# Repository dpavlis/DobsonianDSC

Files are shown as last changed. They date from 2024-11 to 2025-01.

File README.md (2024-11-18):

# DobsonianDSC

---
### High-light of changes implemented compared to original
* Support for buzzer to indicate the system is up and additional signals
* Support for reset-switch to reset counters of encoders and reset the whole system (if long-pressed)
* Configuration extended to enable setting starting points of encoder counters (to allow setting different than 0 count - for example, if the default position of the scope is towards Zenith)
---
Amateur astronomers want to know where their telescope is pointing at. For this reason, many commercial telescopes (like the Orion IntelliScope) come equipped with "push to" features, often based on high precision optical rotary encoders attached to the telescope mount, and a hand control device with a database of coordinates of thousands of stars and other sky objects.

There are also commercial Digital Setting Circles, which are kits sold for telescope owners to adapt to their existing telescope, in order to give it "push to" features, costing a few hundred dollars.

The mobile app [SkySafari](https://skysafariastronomy.com/) comes with a celestial database that is often more up-to-date, and it's user interface (a visual representation of the night sky) can be considered superior to what text lines on a push-to hand controller allow.

This project is an open source implementation of Digital Setting Circles for dobsonian telescopes. By using two inexpensive optical encoders and an ESP32 microcontroller it enables amateur astronomers to connect their dobsonian telescope to the SkySafari app.

Particular emphasis has been placed on making sure anybody can build the circuit regardless of their experience (or lack thereof) with electronics or arduino, including a step-by-step guide for a very simple implementation that requires no soldering.

This DSC achieves the following:

* Absolute minimum number of components, making it simple and inexpensive. (The bill of materials is under **$40**)
* Easy to build, no soldering required.
* Wireless communication with the SkySafari app, No need for a wired handheld control.
* Ability to connect to an external WiFi (to maintain access to the internet while using the DSC)
* Web configuration page for easily configuring everything: WiFi settings/password, encoder resolutions, flipping encoder pins, notification API/keys, device name.
* Bluetooth support.

This is what it looks like installed on a small tabletop dobsonian:

Mini Dob with DSC

## Documentation

  * This [Arduino IDE guide](https://github.com/vlaate/DobsonianDSC/blob/master/docs/ArduinoIDE.md) will provide beginner-friendly step by step instructions on how to install and configure the Arduino IDE on your computer, including the board managers and libraries required by the DSC, so that you can upload this software to an ESP-32 microcontroller.
  * This [Upload and Configuration guide](https://github.com/vlaate/DobsonianDSC/blob/master/docs/UploadConfigure.md) provides step by step instructions on how to upload the DSC software to the ESP32 microcontroller, how to configure the DSC using it's web configuration interface, and how to connect the SkySafari app to it.
  * The [Circuit Building Guide](https://github.com/vlaate/DobsonianDSC/blob/master/docs/Solderless.md) contains the circuit schematics, the parts list and a step-by-step instructions on how to assemble a beginner-friendly **solderless** implementation of the circuit.
  * You can ask questions or provide feedback in the [CloudyNights forums](https://www.cloudynights.com/topic/589521-37-dobsonian-dsc-for-diy-makers/).
  * Useful information on how to attach altitude encoders to dobsonians can be found [here](https://www.cloudynights.com/topic/772803-how-to-attach-altitude-encoders-to-dobsonians/)

## Pictures

Close up AZ
Alt Encoder 1
Alt Encoder 2
Components
Web Configuration

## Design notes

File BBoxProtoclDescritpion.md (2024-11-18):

# Known DSC Commands

Thanks to https://github.com/synfinatic/teensy-dsc for following summary:

### BBox/Sky Wizard CTI
 
Command | Description | Example Input | Example Output | Notes
--------|-------------|---------------|----------------|------
Z# # | Set encoder resolution | R10000\<TAB\>-10000\<CR\> | * | RA/Az, Dec/Alt
P | Status | P | 001 | Hard coded value to mean no errors, battery OK
Q | Get encoder position | Q | +01234\<TAB\>-00045\<CR\> | 

Notes:

 * Each numerical value must be 6 characters.
 * Unclear if both \<Tab\> and \<SP\> are allowed, but I think so.  Tabs are preferred?

### Orion Intelliscope 
 
Command | Description | Example Input | Example Output | Notes
--------|-------------|---------------|----------------|------
Q | Get encoder position | Q | +01234\<TAB\>-00045\<CR\> | 
P | Status | P | P001 | Hard coded value to mean no errors, battery OK

Notes:

 * At startup, the Intelliscope sends it's version string: V1.14
 * Each numerical value must be 6 characters.

### NGC Max
 
Command | Description | Example Input | Example Output | Notes
--------|-------------|---------------|----------------|------
Q | Get encoder position | Q | +01234\<TAB\>-00045 | Unlike Intelliscope, no \<CR\> at the end

### Basic Encoder System????

Command | Description | Example Input | Example Output | Notes
--------|-------------|---------------|----------------|------
v | Version | v | TeensyDSC v1.0\<CR\> |
V | Version | V | TeensyDSC v1.0\<CR\> |
R# # | Set encoder resolution | R10000 -10000\<CR\> | R | RA/Az, Dec/Alt
H | Get encoder resolution | H | 10000 -10000\<CR\> | 
r | Get encoder resolution | r | 10000 -10000\<CR\> |
A | Check connection | A | Y |
a | Check connection | a | Y |

### Additional TeensyDSC Commands

Command | Description | Example Input | Example Output | Notes
--------|-------------|---------------|----------------|------
? | CLI Help | ? | \<multiple lines...\> |

### Ouranos / Sky Guider III

Command | Description | Example Input | Example Output | Notes
--------|-------------|---------------|----------------|------
Q | Get encoder position | Q | +01234\<TAB\>-00045\<CR\> | Unsure about Tab/CR
R# # | Set encoder resolution | R10000 -10000 | R | RA/Az, Dec/Alt.  Unsure about Tab/CR 
I# # | Set encoder position | I0 0 | R | Unsure about Tab/CR
A | Set init flag | A | \<Unknown\> | No need to support
a | Get init flag | a | \<Unknown\> | No need to support

---

Thanks to ChatGPT for following summary ;-)

# BBox Protocol for Telescope Control

The BBox protocol is a communication standard used by telescope control systems and digital setting circles (DSCs) to interface with astronomy software for precise control and tracking of celestial objects. It operates over a serial connection (often RS-232) and allows the software to receive and interpret data from encoders mounted on the telescope's axes. The protocol includes commands for querying and configuring the telescope's position, encoder settings, and other operational parameters.

## Key Commands in the BBox Protocol

### 1. Q Command (Query Encoder Position)
- **Purpose**: Retrieves the current encoder counts for the azimuth (horizontal) and altitude (vertical) axes, representing the telescope's pointing position.
- **Command Format**:

Q

- **Response Format**:

azimuth_count, altitude_count

- **Example Interaction**:
- **Sent Command**: `Q`
- **Response**: `123456,654321`
- Here, `123456` is the encoder count for the azimuth axis, and `654321` is the encoder count for the altitude axis. These counts are used by the software to determine the telescope's exact pointing coordinates.

### 2. H Command (Set Home Position)
- **Purpose**: Resets or defines a "home" or reference position for the telescope’s encoders.
- **Command Format**:

H

- **Response Format**:

OK

- **Example Interaction**:
- **Sent Command**: `H`
- **Response**: `OK`
- `OK` confirms that the home position has been set successfully. This position can be used as a baseline for alignment or recalibration purposes.

### 3. G Command (Get Encoder Resolution)
- **Purpose**: Retrieves the encoder resolution, which represents the number of steps per full revolution for each axis.
- **Command Format**:

G

- **Response Format**:

azimuth_resolution, altitude_resolution

- **Example Interaction**:
- **Sent Command**: `G`
- **Response**: `4096,8192`
- Here, `4096` is the azimuth resolution, and `8192` is the altitude resolution, representing the number of encoder steps per revolution for each axis.

### 4. Z Command (Reset Encoders)
- **Purpose**: Resets the encoder counts to zero or a predefined starting position.
- **Command Format**:

Z

- **Response Format**:

OK

- **Example Interaction**:
- **Sent Command**: `Z`
- **Response**: `OK`
- This response confirms that the encoder counts have been reset successfully. After resetting, the telescope is ready for further alignment or movement instructions.

### 5. S Command (Set Encoder Resolution)
- **Purpose**: Configures the encoder resolution, specifying the number of steps per full revolution for both azimuth and altitude axes.
- **Command Format**:

S azimuth_resolution, altitude_resolution

- **Response Format**:

OK

- **Example Interaction**:
- **Sent Command**: `S 4096,8192`
- **Response**: `OK`
- This confirms that the encoder resolution has been set to 4096 steps per revolution for the azimuth axis and 8192 steps per revolution for the altitude axis.

### 6. T Command (Toggle Tracking)
- **Purpose**: Enables or disables tracking to keep the telescope aligned with a specific celestial object.
- **Command Format**:

T on/off

- **Response Format**:

OK

- **Example Interaction**:
- **Sent Command**: `T on`
- **Response**: `OK`
- This indicates that tracking has been enabled. Similarly, sending `T off` would disable tracking.

### 7. C Command (Set Calibration)
- **Purpose**: Applies a calibration factor or offset to correct for mechanical inaccuracies in the telescope mount or encoder setup.
- **Command Format**:

C calibration_value

- **Response Format**:

OK

- **Example Interaction**:
- **Sent Command**: `C 5`
- **Response**: `OK`
- This confirms that a calibration factor of 5 has been applied.

### 8. E Command (Error Query)
- **Purpose**: Retrieves any error codes or status flags from the digital setting circle, assisting with diagnostics or troubleshooting.
- **Command Format**:

E

- **Response Format**:

error_code

- **Example Interaction**:
- **Sent Command**: `E`
- **Response**: `0`
- A response of `0` typically means no error is present. Non-zero values would indicate specific error codes, which may require consulting device documentation for interpretation.

## Summary of Common Command Responses

| Command | Description | Example Sent | Example Response |
|---|---|---|---|
| `Q` | Query Encoder Position | `Q` | `123456,654321` |
| `H` | Set Home Position | `H` | `OK` |
| `G` | Get Encoder Resolution | `G` | `4096,8192` |
| `Z` | Reset Encoders | `Z` | `OK` |
| `S` | Set Encoder Resolution | `S 4096,8192`| `OK` |
| `T` | Toggle Tracking | `T on` | `OK` |
| `C` | Set Calibration | `C 5` | `OK` |
| `E` | Error Query | `E` | `0` |

Each command in the BBox protocol plays a crucial role in aligning, configuring, and operating the telescope. By understanding the function and response format of each command, users can accurately control and adjust the telescope’s movement, alignment, and tracking capabilities with compatible software applications.

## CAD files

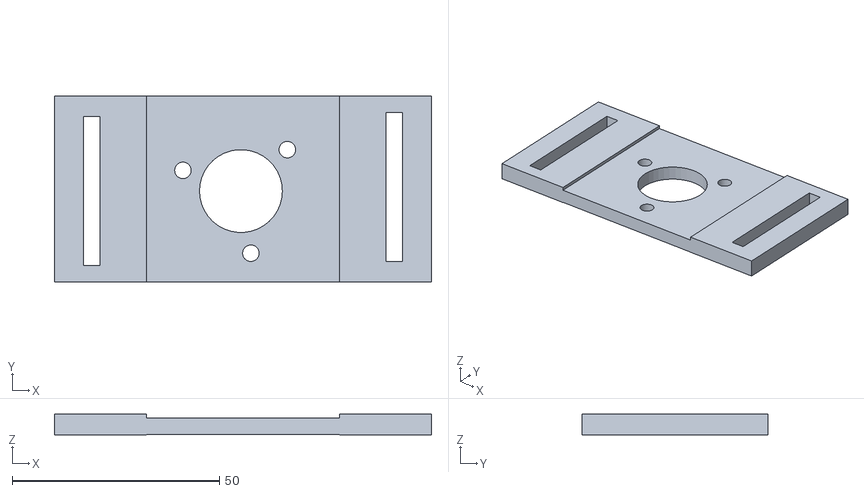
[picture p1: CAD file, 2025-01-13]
STLs/HolderScientific.stl
91.0 x 45.0 x 5.05

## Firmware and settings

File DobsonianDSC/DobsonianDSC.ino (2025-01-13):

/*
  Dual Encoder Digital Setting Circles for ESP32 microcontrollers

  This is a simple adapter to connect two inexpensive incremental optical encoders
  via WiFi and/or BlueTooth to astronomy apps such as SkySafari,
  in order to provide "Push To" style features to dobsonian style telescope mounts.

  Copyright (c) 2017-2021 Vladimir Atehortúa. All rights reserved.

  This program is free software: you can redistribute it and/or modify
  it under the terms of the version 3 GNU General Public License as
  published by the Free Software Foundation.
  This program is distributed in the hope that it will be useful,
  but WITHOUT ANY WARRANTY; without even the implied warranty of
  MERCHANTABILITY or FITNESS FOR A PARTICULAR PURPOSE.  See the
  GNU General Public License for more details.
  You should have received a copy of the GNU General Public License along with this program.
  If not, see <http://www.gnu.org/licenses/>
*/

/**
    Hardware used:
    ESP-32S Development Board, I used a generic one: https://www.aliexpress.com/item/32800930387.html?
    Two Optical Encoders with NPN (a.k.a. "N channel") "Open Collector" (a.k.a. "open drain") output, I used some 600 p/r generic ones: https://www.aliexpress.com/item/32669741048.html
    Dupont cables or other suitable connectors.
    Power supply (could be a 5V USB power bank)

    ESP32 pinout:
     IMPORTANT: Only encoders with NPN Open collector outputs can be connected directly to the pins of the ESP32. Other encoders might require level shifters.
     AZ_Encoder_A = GPIO18 = D18  (or change it in the #define code below)
     AZ_Encoder_B = GPIO19 = D19  (or change it in the #define code below)
     ALT_Encoder_A = GPIO25 = D25 (or change it in the #define code below)
     ALT_Encoder_B = GPIO26 = D26 (or change it in the #define code below)
     VIN = Encoder VCC (and if you don't use a USB power bank, this would also connect to your 5V power source)
     GND = Encoder GND
*/

/**
   Required Additional Board Managers for the Arduino IDE (File->Preferences):
   https://dl.espressif.com/dl/package_esp32_index.json

   Required libraries for the Arduino IDE (Tools -> Manage Libraries):
   ESP32Encoder by Kevin Harrington, see https://github.com/madhephaestus/ESP32Encoder
   ArduinoJson by Benoit Blanchon, see https://arduinojson.org/
*/

#include <WiFi.h>
#include <WebServer.h>
#include <ESPmDNS.h>
#include <HTTPClient.h>
#include <ESP32Encoder.h>
#include "WebConfig_DSC.h"
#include "BluetoothSerial.h"
#include "note_frequencies.h"
#if !defined(CONFIG_BT_ENABLED) || !defined(CONFIG_BLUEDROID_ENABLED)
#error Bluetooth is not enabled! Please run `make menuconfig` to and enable it
#endif

//#define DEBUG_PROTOCOL //for priting debug messages when handling protocol

// Choose which pins of the ESP32 to use for the Azimuth Encoder
ESP32Encoder AZencoder;
#define PIN_AZ_A 18 // Important: Not all encoders can be connected directly to the pins of the ESP32, read more about this in the project's github page
#define PIN_AZ_B 19

#define AZIMUTH_RES 12000 //1000 pulses per revolution, programmed in quadrature for 1000 x 4 = 4000 pulses, geared 1:3 = 12000
#define AZIMUTH_START 0 //starts at 0 - NORTH

// Choose which pins of the ESP32 to use for the Altitude Encoder
ESP32Encoder ALTencoder;
#define PIN_ALT_A 25
#define PIN_ALT_B 26

#define ALTITUDE_RES 22140 //ticks per rotation : 1000 x 4 = 4000 pulses, geared ??
#define ALTITUDE_START 5624  //starts at 5624  - 90+ degrees (parked)

#define AP_WIFI_NETWORK "ExploreScientific_DSC"

#define MAX_SRV_CLIENTS  3   // How many clients can connect simultaneously to the DSC.
#define MAX_REQUEST_LENGTH 30 // Maximum length of request from client to process 

//beeper for signalling
#define PIN_BEEPER 32
//count-reset button
#define PIN_RESET 33
#define RESTART_HOLD_TIME 3000 // 3s - 3000ms
#define PIN_RESET_WAIT_TIME 50

unsigned int melodyStart[] = {NOTE_C, NOTE_E, NOTE_G, NOTE_0, NOTE_C, NOTE_E, NOTE_G, NOTE_FINISH};
unsigned int melodyError[] = {NOTE_C, NOTE_C, NOTE_G, NOTE_G, NOTE_C, NOTE_C, NOTE_G, NOTE_G, NOTE_FINISH};
unsigned int melodySetupCompleted[] = {NOTE_C, NOTE_0, NOTE_C, NOTE_0, NOTE_C, NOTE_0, NOTE_G, NOTE_G, NOTE_G, NOTE_G, NOTE_FINISH};

BluetoothSerial SerialBT;

String params = "["
                "{"
                "'name':'ssid',"
                "'label':'WiFi SSID Name',"
                "'type':" + String(INPUTTEXT) + ","
                "'default':''"
                "},"
                "{"
                "'name':'pwd',"
                "'label':'WiFi Password',"
                "'type':" + String(INPUTPASSWORD) + ","
                "'default':''"
                "},"
                "{"
                "'name':'btname',"
                "'label':'Bluetooth device Name',"
                "'type':" + String(INPUTTEXT) + ","
                "'default':'Telescope'"
                "},"
                "{"
                "'name':'azsteps',"
                "'label':'Azimuth Steps',"
                "'type':" + String(INPUTNUMBER) + ","
                "'min':1,'max':10000000,"
                "'default':'" + AZIMUTH_RES + "'"
                "},"
                "{"
                "'name':'azstart',"
                "'label':'Azimuth Start Position',"
                "'type':" + String(INPUTNUMBER) + ","
                "'min':0,'max':10000000,"
                "'default':'" + AZIMUTH_START + "'"
                "},"
                "{"
                "'name':'alsteps',"
                "'label':'Altitude Steps',"
                "'type':" + String(INPUTNUMBER) + ","
                "'min':1,'max':10000000,"
                "'default':'"+ ALTITUDE_RES + "'"
                "},"
                "{"
                "'name':'alstart',"
                "'label':'Altitude Start Position',"
                "'type':" + String(INPUTNUMBER) + ","
                "'min':0,'max':10000000,"
                "'default':'"+ ALTITUDE_START + "'"
                "},"
                "{"
                "'name':'flpaz',"
                "'label':'Flip Azimuth',"
                "'type':" + String(INPUTCHECKBOX) + ","
                "'default':'1'"
                "},"
                "{"
                "'name':'flpalt',"
                "'label':'Flip Altitude',"
                "'type':" + String(INPUTCHECKBOX) + ","
                "'default':'1'"
                "},"
                "{"
                "'name':'apikey',"
                "'label':'Notification API Key (optional)',"
                "'type':" + String(INPUTTEXT) + ","
                "'max':35,"
                "'default':''"
                "},"
                "{"
                "'name':'userkey',"
                "'label':'Notification User Key (optional)',"
                "'type':" + String(INPUTTEXT) + ","
                "'max':35,"
                "'default':''"
                "}"
                "]";

WebServer server;
WiFiServer TCPserver(4030);                 // 4030 is the TCP port Skysafari usually expects for "Basic Encoder Systems"
WiFiClient serverClients[MAX_SRV_CLIENTS];
WebConfig conf;

boolean initWiFi() {
  boolean connected = false;
  WiFi.mode(WIFI_STA);
  Serial.print("Connecting to ");
  Serial.print(conf.values[0]);
  Serial.println(" SSID");
  if (conf.values[0] != "") {
    WiFi.begin(conf.values[0].c_str(), conf.values[1].c_str());
    uint8_t cnt = 0;
    while ((WiFi.status() != WL_CONNECTED) && (cnt < 20)) {
      delay(500);
      Serial.print(".");
      cnt++;
    }
    Serial.println();
    if (WiFi.status() == WL_CONNECTED) {
      Serial.print("IP Adress:");
      Serial.println(WiFi.localIP());
      connected = true;
      // We can use the Pushover service to send a notification to your smartphone, an easy way to obtain the IP address that was assigned to the device:
      if (conf.getValue("apikey") != "" && conf.getValue("userkey") != "")
      {
        HTTPClient http;
        http.begin("https://api.pushover.net/1/messages.json");
        http.addHeader("Content-Type", "application/x-www-form-urlencoded");
        char _header[300];
        sprintf(_header, "token=%s&user=%s&message=Telescope-DSC connected to SSID:[%s] IP Address: [%s]", conf.getValue("apikey"), conf.getValue("userkey"), WiFi.SSID(), WiFi.localIP().toString().c_str());
        int httpResponseCode = http.POST(_header);
        http.end();
      }
    }
  }
  if (!connected) { // if unable to connect to an external WiFi, let's launch our own passwordless WiFi SSID:
    WiFi.mode(WIFI_AP);
    WiFi.softAP(AP_WIFI_NETWORK, "", 1);
  }
  return connected;
}

// method that handles the clicks on "SAVE" and "RESET" buttons on the web config form
void handleRoot() {
  conf.handleFormRequest(&server);
  if (server.hasArg("SAVE"))
  {
    uint8_t cnt = conf.getCount();
    for (uint8_t i = 0; i < cnt; i++)
    {
      Serial.print(conf.getName(i));
      Serial.print(" = ");
      Serial.println(conf.values[i]);
    }
  }
}

/**
   Configure encoders using the ESP32Encoder library by Kevin Harrington.
   This uses the ESP32's hardware pulse counters, not polling nor interrupts!
   In my tests, two encoders can get simultaneous quadrature pulses at 20Khz without missing a step.
*/
void setupEncoders()
{
  // It's very important to enable pull up resistors in order to work with the NPN open collector outputs:
  ESP32Encoder::useInternalWeakPullResistors = puType::up;

  // flip the pins used by Altitude encoder if the web configuration says so:
  if (conf.getBool("flpalt"))
  {
    ALTencoder.attachFullQuad(PIN_ALT_A, PIN_ALT_B);
  }
  else
  {
    ALTencoder.attachFullQuad(PIN_ALT_B, PIN_ALT_A);
  }
  ALTencoder.setFilter(0); // filters are only needed for cheap mechanical/switch encoders such as the Keyes KY-040, not by the 600p/s encoders

  // flip the pins used by Azimuth encoder if the web configuration says so:
  if (conf.getBool("flpaz"))
  {
    AZencoder.attachFullQuad(PIN_AZ_B, PIN_AZ_A);
  }
  else
  {
    AZencoder.attachFullQuad(PIN_AZ_A, PIN_AZ_B);
  }
  AZencoder.setFilter(0); // filters are only needed for cheap mechanical/switch encoders such as the Keyes KY-040, not by the 600p/s encoders

  // set starting count value after attaching
  ALTencoder.clearCount(); //reset counter
  ALTencoder.setCount(conf.getInt("alstart")); //set starting point
  AZencoder.clearCount();
  AZencoder.setCount(conf.getInt("azstart"));
}

void processBBoxCommand(char command,char details[], char response[]) 
{
   switch (command)
        {
          case 'Q':   // the Query command, sent by SkySafari and others as the "Basic Encoder protocol" to query for encoder values.
            sprintf(response, "%lld\t%lld\t\n", AZencoder.getCount(), ALTencoder.getCount());
            break;
          case 'G': // G Command (Get Encoder Resolution) -- duplicate to 'H' ??
            snprintf(response, 20, "%d-%d\n", conf.getInt("azsteps"), conf.getInt("alsteps"));
            break;
          case 'H':   // 'H' - request for encoder resolution, e.g. 10000-10000\n
            //snprintf(response, 20, "%d-%d\n", conf.getInt("azsteps"), conf.getInt("alsteps"));
            snprintf(response, 20, "%d\t%d\t\n", conf.getInt("azsteps"), conf.getInt("alsteps"));
            break;
          case 'Z': // 'Z' - Z Command (Reset Encoders)
            ALTencoder.clearCount();
            AZencoder.clearCount();
            sprintf(response, "OK\n");
            break;
          case 'S': // 'S' S Command (Set Encoder Resolution) - S azimuth_resolution, altitude_resolution
            //S azimuth_resolution, altitude_resolution
            int altRes, azRes;
            if (sscanf(details, "%d,%d", &azRes, &altRes) == 2) {
              char strval[20];
              itoa(azRes,strval,10);
              conf.setValue("azsteps",strval);
              itoa(altRes,strval,10);
              conf.setValue("alsteps",strval);
              sprintf(response, "OK\n");
            }
            break;
          case 'R': // Not A BBox command - reset counters (for debugging mostly)
            ALTencoder.clearCount(); 
            AZencoder.clearCount();
            sprintf(response, "OK\n");
            break;
          default: sprintf(response,"\n");
            #ifdef DEBUG_PROTOCOL
              Serial.print("*** UNKNOWN COMMAND ****");
            #endif
        }
    #ifdef DEBUG_PROTOCOL
    Serial.printf("[%c]{%s}(%s)\n",command,details,response);
    #endif

}

void attendTcpRequests()  // handle connections from SkySafari and similar software via TCP on port 4030
{
  uint8_t i;
  // check for new clients trying to connect
  if (TCPserver.hasClient()) {
    for (i = 0; i < MAX_SRV_CLIENTS; i++) {
      // find a free or disconnected spot:
      if (!serverClients[i] || !serverClients[i].connected()) {
        if (serverClients[i]) {
          serverClients[i].stop();
        }
        serverClients[i] = TCPserver.available();
        // the new client has connected
        #ifdef DEBUG_PROTOCOL
          Serial.print("New client connected: ");
          Serial.println(serverClients[i].remoteIP());
        #endif
        break;
      }
    }
    // when there are no free/disconnected spots, reject the new client:
    if (i == MAX_SRV_CLIENTS) {
      WiFiClient serverClient = TCPserver.available();
      serverClient.stop();
      #ifdef DEBUG_PROTOCOL
          Serial.println("Client rejected. No more free spots.");
      #endif
    }
  }

  // check what the client sends for "Basic Encoder protocol" commands:
  for (i = 0; i < MAX_SRV_CLIENTS; i++)
  {
    if (serverClients[i] && serverClients[i].connected())
    {
      if (serverClients[i].available())
      {
        #ifdef DEBUG_PROTOCOL
        Serial.printf("TCP [%s:%u]",serverClients[i].remoteIP().toString(),serverClients[i].remotePort());
        #endif
        char command = serverClients[i].read(); // read the first character received, usually the command
        char requestDetails[MAX_REQUEST_LENGTH+1];
        int count=0;
        if (serverClients[i].available() && count < MAX_REQUEST_LENGTH){
          requestDetails[count] = serverClients[i].read();
          count++;
        }
        requestDetails[count]='\0';
        while (serverClients[i].available())
        {
            serverClients[i].read(); // flushing the remaining input buffer (if there are more chars than fit to request details)
        }
        char response[30];
        processBBoxCommand(command,requestDetails,response);
        serverClients[i].println(response);
      }
    }
  }
}

void attendBTRequests()   // handle connections from SkySafari and similar software via BlueTooth
{
  if (SerialBT.available()) {
    //WiFi.disconnect();
    //WiFi.mode(WIFI_OFF);

    char command = SerialBT.read();
    char requestDetails[MAX_REQUEST_LENGTH+1];
    int count=0;
    while (SerialBT.available() && count < MAX_REQUEST_LENGTH)
    {
      requestDetails[count] = SerialBT.read();
      count++;
    }
    requestDetails[count]='\0';
    while (SerialBT.available())
    {
      SerialBT.read();  // flushing the remaining input buffer (if there are more chars than fit to request details)
    }

    #ifdef DEBUG_PROTOCOL
    Serial.print("BT: ");
    #endif
    char response[30];
    processBBoxCommand(command,requestDetails,response);

    #ifdef DEBUG_PROTOCOL
    if (command=='?') printConfig();
    #endif

    SerialBT.println(response);
  }
}

void printConfig(){
    for(int i=0; i<conf.getCount();i++){
      SerialBT.print(conf.getName(i));
      SerialBT.print(" : ");
      SerialBT.println(conf.getValue(conf.getName(i).c_str()));
    }
}

void playMelody(const unsigned int melody[]){
   for(int i=0; melody[i]!=NOTE_FINISH; i++){
     tone(PIN_BEEPER, melody[i], 300);
   }
}

/**
 * Arduino main setup method
 */
void setup() {
  Serial.begin(115200);
  Serial.println(params);
  playMelody(melodyStart);
  pinMode(PIN_RESET, INPUT_PULLDOWN);

  conf.setDescription(params);
  conf.readConfig();
  initWiFi();
  char dns[30];
  sprintf(dns, "%s.local", conf.getApName());
  if (MDNS.begin(dns))
  {
    Serial.println("DNS active");
  }
  server.on("/", handleRoot);
  server.begin(80); // starts web server for configuration page

  TCPserver.begin(); // starts TCP server for skysafari via WiFi

  setupEncoders();

  if (conf.getValue("btname") != "")  // starts Bluetooth service only if a name has been configured for our device
  {
    SerialBT.begin(conf.getValue("btname"));
    Serial.println("BT started");
  }
  playMelody(melodySetupCompleted);

}

void loop() 
{
  if (digitalRead(PIN_RESET) == HIGH)
  {
    //reset counters - AZ - 0 ; ALT - 0
    ALTencoder.clearCount(); 
    AZencoder.clearCount();
    Serial.println("ALT&AZ counters zeroed");
    tone(PIN_BEEPER, NOTE_A2);
    delay(300);
    noTone(PIN_BEEPER);
    delay(2000);
    if (digitalRead(PIN_RESET) == HIGH)
    {
      Serial.println("Going to restart");
      tone(PIN_BEEPER, NOTE_A);
      delay(600);
      ESP.restart();      
    }
  }
  server.handleClient();
  attendBTRequests();
  attendTcpRequests();
}

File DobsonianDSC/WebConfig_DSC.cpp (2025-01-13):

/*

  Original file: WebConfig.cpp version 1.4
  Author Gerald Lechner lechge@gmail.com https://github.com/GerLech
  Licensed under the GNU Lesser General Public License v3.0

  This library builds a web page with a smart phone friendly form to edit
  a free definable number of configuration parameters. The submitted data will bestored in the SPIFFS
  The library works with ESP8266 and ESP32

  It has been modified by Vladimir Atehortúa to customize the HTML styles for 
  astronomy/night use (dark background with red colors) for the Digital Setting Circles project
  which is released under the compatible GPLv3
  
  This program is free software: you can redistribute it and/or modify
  it under the terms of the version 3 GNU General Public License as
  published by the Free Software Foundation.
  This program is distributed in the hope that it will be useful,
  but WITHOUT ANY WARRANTY; without even the implied warranty of
  MERCHANTABILITY or FITNESS FOR A PARTICULAR PURPOSE.  See the
  GNU General Public License for more details.
  You should have received a copy of the GNU General Public License along with this program.
  If not, see <http://www.gnu.org/licenses/>
*/

#include "WebConfig_DSC.h"
#include <Arduino.h>
#if defined(ESP32)
  #include "SPIFFS.h"
  #include <WebServer.h>
#else
  #include <ESP8266WebServer.h>
#endif
#include <ArduinoJson.h>
#include <FS.h>
#include <WiFi.h>

const char * inputtypes[] = {"text","password","number","date","time","range","check","radio","select","color","float"};

//HTML templates
//Template for header and begin of form
const char HTML_START[] PROGMEM =
"<!DOCTYPE HTML>\n"
"<html lang='en'>\n"
"<head>\n"
"<meta http-equiv='Content-Type' content='text/html; charset=utf-8'>\n"
"<meta name='viewport' content='width=320' />\n"
"<title>ExploreScientific-DSC</title>\n"
"<style>\n"
"body {\n"
"  background-color: #000000;\n"
"  font-family: Arial, Helvetica, Sans-Serif;\n"
"  Color: #bb0000;\n"
"  font-size:12pt;\n"
"  width:320px;\n"
"}\n"
".titel {\n"
"font-weight:bold;\n"
"text-align:center;\n"
"width:100%%;\n"
"padding:5px;\n"
"}\n"
".zeile {\n"
"  width:100%%;\n"
"  padding:5px;\n"
"  text-align: center;\n"
"}\n"
"button {\n"
"font-size:14pt;\n"
"width:150px;\n"
"border: none;\n"
"border-radius: 4px;\n"
"margin:5px;\n"
"background-color: red;\n"
"color: black;\n"
"}\n"
"input[type] {\n"
"background-color: #ffaaaa;\n"
"border: none;\n"
"}\n"
"textarea:focus, input:focus{\n"
"outline: 2px solid red;\n"
"}\n"
"input[type=checkbox] {\n"
"filter: hue-rotate(150deg);\n"
"}\n"
"</style>\n"
"</head>\n"
"<body>\n"
"<svg style=\"fill: red; width: 50%; display: block; margin: auto;\" xmlns=\"http://www.w3.org/2000/svg\" viewBox=\"0 0 180 156\"><path d=\"M0 80.2V78l6.6-2.8-3-7.2 7.4-3.2 3 7.4 21.4-8.8.8-5.8 87.6-36.2 1-5.8C143.4 7.8 162 0 163 0c7 0 17 16.8 17 30 0 4.4-1.4 6.6-3 7.2l-37 15.4-4.6-3.6-26 10.8-.2 4.4-7.4 3 2 5c3.6 1.4 5.6 3.2 7.2 6.8l35.2 75.6-3.2 1.4-37.2-65-3.2 53h-3.2l-3.6-53L59 156l-3.2-1.4 36.4-78.8-1.4-4-7.4 3.2-3.4-3-32.4 13.4L43 82l-19.4 8zM162 9c0 9.4 7.8 23.8 12.4 23.8 1.2 0 2.4-1.2 2.4-4.8 0-8-7.6-23.2-12.4-23.2-1.4 0-2.4 1-2.4 4.2z\"/></svg>\n"
"<div id='main_div' style='margin-left:15px;margin-right:15px;'>\n"
"<div class='titel'>ExploreScientific DSC</div>\n"
"<form method='post'>\n";

//Template for one input field
const char HTML_ENTRY_SIMPLE[] PROGMEM =
"  <div class='zeile'><b>%s</b></div>\n"
"  <div class='zeile'><input type='%s' value='%s' name='%s'></div>\n";
const char HTML_ENTRY_AREA[] PROGMEM =
"  <div class='zeile'><b>%s</b></div>\n"
"  <div class='zeile'><textarea rows='%i' cols='%i' name='%s'>%s</textarea></div>\n";
const char HTML_ENTRY_NUMBER[] PROGMEM =
"  <div class='zeile'><b>%s</b></div>\n"
"  <div class='zeile'><input type='number' min='%i' max='%i' value='%s' name='%s'></div>\n";
const char HTML_ENTRY_RANGE[] PROGMEM =
"  <div class='zeile'><b>%s</b></div>\n"
"  <div class='zeile'>%i&nbsp;<input type='range' min='%i' max='%i' value='%s' name='%s'>&nbsp;%i</div>\n";
const char HTML_ENTRY_CHECKBOX[] PROGMEM =
"  <div class='zeile'><b>%s</b><input type='checkbox' %s name='%s'></div>\n";
const char HTML_ENTRY_RADIO_TITLE[] PROGMEM =
" <div class='zeile'><b>%s</b></div>\n";
const char HTML_ENTRY_RADIO[] =
"  <div class='zeile'><input type='radio' name='%s' value='%s' %s>%s</div>\n";
const char HTML_ENTRY_SELECT_START[] PROGMEM =
" <div class='zeile'><b>%s</b></div>\n"
" <div class='zeile'><select name='%s'>\n";
const char HTML_ENTRY_SELECT_OPTION[] PROGMEM =
"  <option value='%s' %s>%s</option>\n";
const char HTML_ENTRY_SELECT_END[] PROGMEM =
" </select></div>\n";
const char HTML_ENTRY_MULTI_START[] PROGMEM =
" <div class='zeile'><b>%s</b></div>\n"
" <div class='zeile'><fieldset style='text-align:left;'>\n";
const char HTML_ENTRY_MULTI_OPTION[] PROGMEM =
"  <input type='checkbox' name='%s', value='%i' %s>%s<br>\n";
const char HTML_ENTRY_MULTI_END[] PROGMEM =
" </fieldset></div>\n";
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

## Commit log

2024-11-14 added handling of push-button and sound; extended config by adding initial alt&az position options
2025-01-13 Updated for ExploreScientific 12". Mostly parameter changes & names
    [HolderScientific.stl]
